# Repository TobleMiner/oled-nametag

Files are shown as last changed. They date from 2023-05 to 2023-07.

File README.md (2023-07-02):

OLED Nametag
============

This repository contains the design file for a fully open source
electronic name badge with monochrome OLED display.  

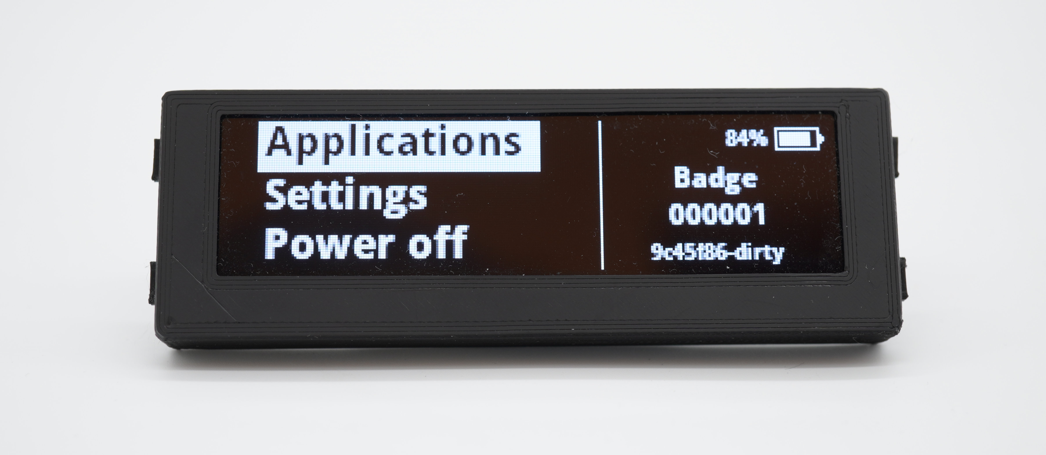
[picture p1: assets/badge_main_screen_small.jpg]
Image of badge in operation


**I would not recommend ordering RevA yet as there are a number of
issues with that version. See
[Rev A issues](https://github.com/TobleMiner/oled-nametag#rev-a-issues)
for details.**

# Features

 - Bright, sunlight readable OLED display
 - Infinity constrast ratio
 - Support for GIF animations
 - WLAN AP support
 - Web interface for management of animations
 - Automatic brightness adjustment
 - 8h+ runtime

# Construction

All fabrication files are located in `fab`.  

## PCB

The main PCB have been optimized for manufacturing through JLCPCB.  
Most components can also be assmbled by JLCPCB directly.  

## Display

The display used can be one of:
 - UG-5664ALBEF01
 - UG-5664ASWEF01
 - ER-OLED032-1 (all variants)

Other menchanically compatible SSD1322-based parts can also be used.

## Housing

The device housing is 3D printable and designed to suit most 3D printing
processes, especially SLA and FDM. Good results have also been achieved with
MJF and SLS printing.  

There are three different fabrication files for the case top part,
depending on the thickness of the lithium batteries used.  

Additionally 4 button actuators need to be printed for each OLED badge.
Those are also contained in the OpenSCAD design files and fabrication
output.

# Assembly

## PCB

When choosing PCB assembly through JLCPCB only two PCB components need to
be assmbled manually:
 - WLAN antenna (AE1)
 - Ambient light sensor (U4)

## Display

The display is mounted to the top side of the PCB using double sided
adhesive tape with a thickness of .15mm. Align to top of the PCB (side
with USB-C port) with the top of the display.

## Batteries

The device needs two 303030, 403030 or 503030 cells as a power source.  
The batteries need to be mounted on the bottom side of the PCB. Double-
sided adhesive foam tape with a thickness of 2mm is recommended for this
purpose.

## Housing

Place the button actuators into the housing first, then slide in the PCB
with both display and batteries attached and stuck down.  

At this point the badge should look like this:  
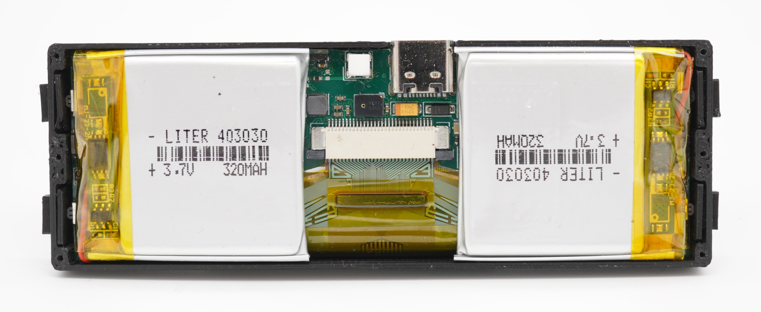
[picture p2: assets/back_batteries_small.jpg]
Image of backside with top removed


Finally screw on the top lid iwht six 4mm M1 fine thread self tapping
screws.

# Firmware

The OLED badge is running fully Open Source firmware. For the purpose of
enabling WLAN connectivity vendor-provided binary blobs are required.  
The firmware source can be found here:  
[https://github.com/TobleMiner/oled-nametag-firmware](https://github.com/TobleMiner/oled-nametag-firmware)

# Rev A issues

Rev A is very much a prototype. It has the following known issues:
 - USB D- and D+ are swapped on the ESP32-S3, needs bodge to swap data lines
 - OLED SPI mode is inconvenient and incompatible with current firmware, connect R1 to GND
 - R21 is too large, preventing soft power down, replace with 1k

The current state of the repository does not reflect Rev A but a
potential Rev B. Please note that this state of the design has not been
tested yet.

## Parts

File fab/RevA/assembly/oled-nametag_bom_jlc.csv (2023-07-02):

Comment | Designator | Footprint | LCSC Part #
10uF | C4,C5,C28,C30,C31,C32,C13,C18,C26 | C_0402_1005Metric | C15525
10uF 25V | C8,C3,C6 | C_0603_1608Metric | C96446
10pF | C11,C12 | C_0402_1005Metric | C32949
1uF | C23,C29,C1,C7,C10,C15,C40 | C_0402_1005Metric | C52923
1nF | C24 | C_1206_3216Metric | C35216
100nF | C25,C27,C34,C35,C36,C37,C38,C2,C39,C9,C14,C16,C17,C21,C22 | C_0402_1005Metric | C1525
10uF | C33 | CP_EIA-3216-10_Kemet-I | C7171
1N5819WS | D2,D1 | D_SOD-323 | C191023
B5819W | D3 | D_SOD-123 | C8598
BAV70 | D4 | SOT-23 | C68978
1N4148WS | D5 | D_SOD-323 | C2128
2A | F2,F3 | R_0603_1608Metric | C96542
Bead | FB1 | L_0805_2012Metric | C1015
USB_C_Receptacle_USB2.0 | J1 | USB_C_Receptacle_Palconn_UTC16-G | C167321
10uH | L1 | L_1210_3225Metric | C703786
0R | L2 | L_0402_1005Metric | C17168
2.2uH | L3 | L_Taiyo-Yuden_MD-3030 | C43389
AO3401A | Q1,Q2 | SOT-23 | C15127
FS8205A | Q3 | SOT-23-6 | C2830320
2N7002 | Q6 | SOT-23 | C8545
680k | R2 | R_0603_1608Metric | C25822
50R | R3 | R_0402_1005Metric | C25120
47k | R4,R10,R11,R21,R6 | R_0402_1005Metric | C25792
0R | R7 | R_0402_1005Metric | C17168
1k | R12,R14 | R_0402_1005Metric | C11702
470R | R13 | R_0402_1005Metric | C25117
10k | R15,R17,R30,R33,R29 | R_0402_1005Metric | C25744
200k | R18 | R_0805_2012Metric | C17539
5.1k | R19,R20,R5,R28,R8,R9,R16,R31 | R_0402_1005Metric | C25905
10mR | R26 | R_0805_2012Metric | C5185583
100R | R27,R22,R23,R24,R25,R32,R1 | R_0402_1005Metric | C25076
Power | SW1 | SW_SPST_B3U-3000P-B | C963349
BTN1 | SW2 | SW_SPST_B3U-3000P-B | C963349
BTN2 | SW3 | SW_SPST_B3U-3000P-B | C963349
BTN3 | SW4 | SW_SPST_B3U-3000P-B | C963349
~ | U1 | FFC_30P_TC_P0.5mm_0.5K-AS-30PWB | C2911772
W25Q128 | U2 | WSON-8-1EP_6x5mm_P1.27mm_EP3.4x4.3mm | C2689660
ESP32-S3 | U3 | QFN-56-1EP_7x7mm_P0.4mm_EP4x4mm_ThermalVias | C2913192
~ | U5 | ST_HCLGA-4LD_3x4mm | C966942
TPS61040DBV | U6 | SOT-23-5 | C7722
DW01+G | U7 | SOT-23-6 | C14213
BQ24081 | U8 | Texas_DRC0010J_ThermalVias | C555156
SRV05-4 | U9 | SOT-23-6 | C85364
BQ27546 | U10 | DSBGA-15_BQ27546_I2C_1.95x2.6mm_P0.5mm | C528629
TPS63001 | U11 | Texas_DRC0010J_ThermalVias | C28060
40MHz | Y1 | Crystal_SMD_2016-4Pin_2.0x1.6mm | C255898

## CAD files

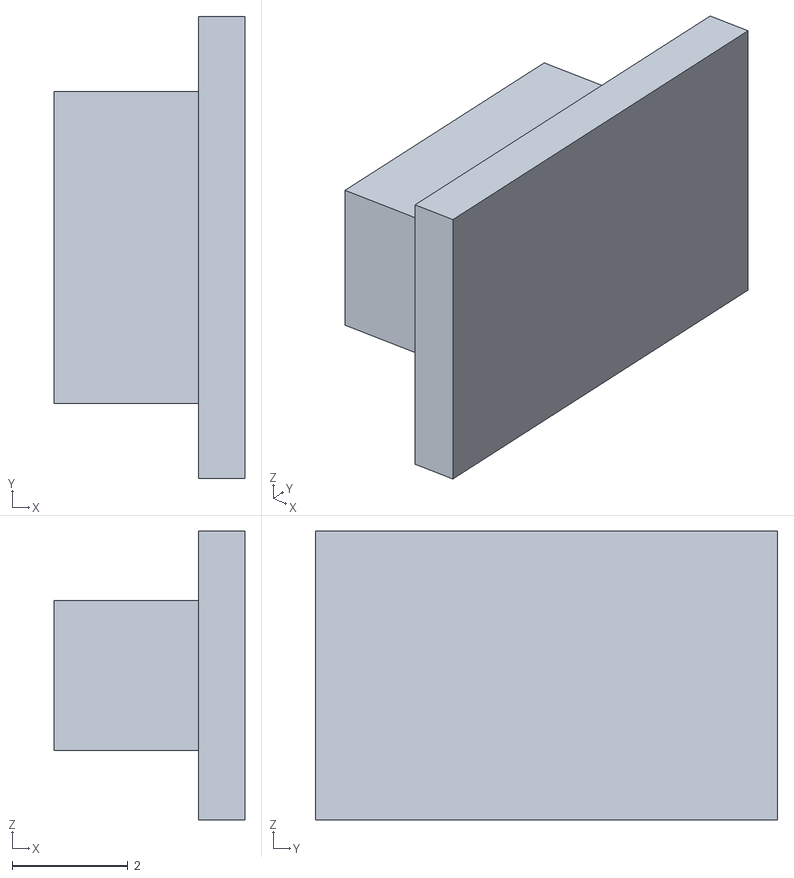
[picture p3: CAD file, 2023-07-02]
fab/RevA/3dprinting/oled-badge-case_button_rev1.4.stl
3.30 x 8.00 x 5.00

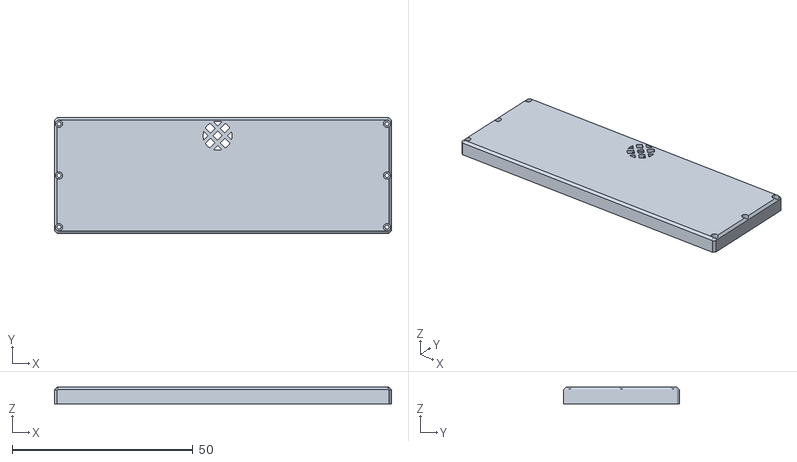
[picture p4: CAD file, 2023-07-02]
fab/RevA/3dprinting/oled-badge-case_top_rev2.1_503030.stl
93.2 x 32.0 x 4.60

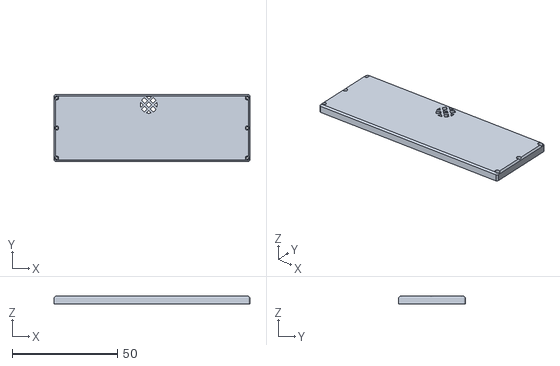
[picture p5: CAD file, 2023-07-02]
fab/RevA/3dprinting/oled-badge-case_top_rev2.1_403030.stl
93.2 x 32.0 x 3.60

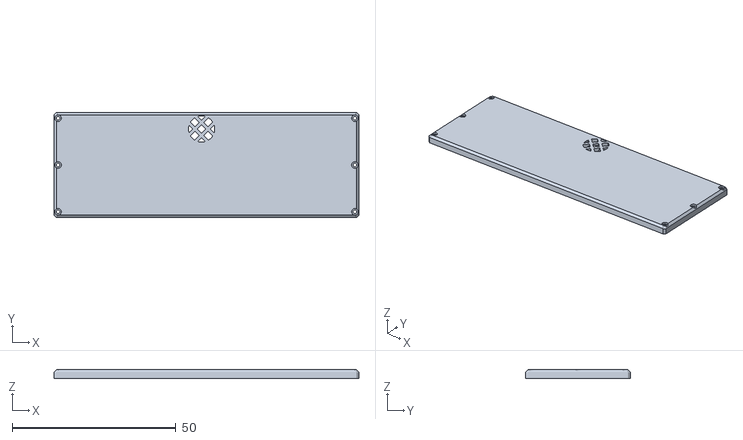
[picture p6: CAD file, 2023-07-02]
fab/RevA/3dprinting/oled-badge-case_top_rev2.1_303030.stl
93.2 x 32.0 x 2.60

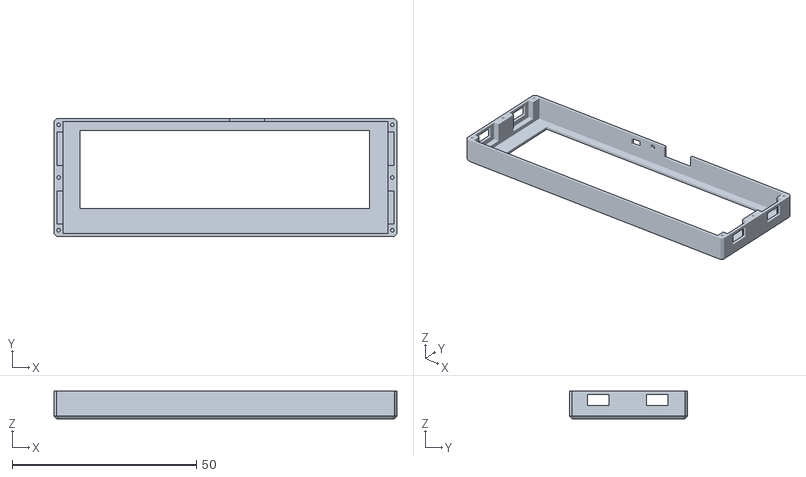
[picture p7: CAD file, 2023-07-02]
fab/RevA/3dprinting/oled-badge-case_bottom_rev1.9_tapered.stl
93.2 x 32.0 x 7.50

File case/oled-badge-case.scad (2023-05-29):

ESCAPE_HOLES = true;
BATTERY_THICKNESS = 4;
WALL_THICKNESS_FRONT_BACK = 0.8;
WALL_THICKNESS_LEFT_RIGHT = 0.8;
WALL_THICKNESS_TOP = 0.8;
WALL_THICKNESS_BOTTOM = 0.8;
BOARD_WIDTH = 88;
BOARD_HEIGHT = 30;
BOARD_DEPTH = 4.5 + BATTERY_THICKNESS;
CASE_HEIGHT_BOTTOM = 6.7;
CASE_HEIGHT_TOP = 0.8 + BATTERY_THICKNESS - 3;
BOARD_OVERSIZE = 0.4;
BUTTON_BASE_THICKNESS = 0.8;
BUTTON_ACTUATOR_LENGTH = 0.8;
BUTTON_ACTUATION = 0.6;
SCREW_HEAD_SIZE = 2; // non-oversized: 2
SCREW_HOLE_SIZE = 1.1; // non-oversized: 1.1
SCREW_THREAD_SIZE = 0.9; // non-oversized: 0.9
/* Anycubic Kossel settings
SCREW_HEAD_SIZE = 2.5; // non-oversized: 2
SCREW_HOLE_SIZE = 1.5; // non-oversized: 1.1
SCREW_THREAD_SIZE = 1; // non-oversized: 0.9
*/

module button() {
    color("brown") {
        translate([0 - 4, 0, -1.5]) cube([4, 5.8, 3]);
        translate([0, 0 - 1.1 - 0.5, -2.5 - 0.5]) cube([BUTTON_BASE_THICKNESS + 0.01, 9, 6]);
    }
}

module button_mirrored() {
    color("brown") {
        translate([BUTTON_BASE_THICKNESS, 0, -1.5]) cube([4, 5.8, 3]);
        translate([-0.01, 0 - 1.1 - 0.5, -2.5 - 0.5]) cube([BUTTON_BASE_THICKNESS + 0.01, 9, 6]);
    }
}

module switch_and_button() {
    translate([0, 0 - 0.6 + 0.1, 0.6]) button();
}

module switch_and_button_mirrored() {
    translate([0, 0 - 0.6 + 0.1, 0.6]) button_mirrored();
}

module board() {
    body_width = BOARD_WIDTH + BOARD_OVERSIZE;
    body_height = BOARD_HEIGHT + BOARD_OVERSIZE;
    translate([0, 0, 2 + 0.15 + 1]) translate([0, 0, 0.5]) {
        // Buttons left
        translate([0, 4.6, 0]) switch_and_button();
        translate([0, 20.6, 0]) switch_and_button();
        translate([BUTTON_BASE_THICKNESS, 4.6, 0]) switch_and_button();
        translate([BUTTON_BASE_THICKNESS, 20.6, 0]) switch_and_button();
    }

    translate([BUTTON_BASE_THICKNESS + BUTTON_ACTUATOR_LENGTH, 0, 0]) {
        // Main body
        cube([body_width, body_height, BOARD_DEPTH]);
        // Display cutout
        translate([0, 2.2, -2]) translate([4.61, 4.62, 0]) cube([78.78, 21.18, 2]);
        translate([0, 0, 2 + 0.15 + 1]) {
            // Antenna
            translate([39, 26, 0]) cube([3, 3, 4]);
            // USB-C port
            translate([45.5 - 0.25, 30, 0]) cube([9.5, 2, 3.6]);
            // Audio port
            // translate([41, 30 + 3, 2]) rotate([90, 0, 0]) cylinder(3, 0.75, 0.75, $fn=100);
            // Light sensor
            translate([33.5, 30, 0.25]) cube([3, 2, 1.5 + 0.5]);
            translate([0, 0, 0.5]) {
                // Buttons right
                translate([body_width, 4.6, 0]) switch_and_button_mirrored();
                translate([body_width, 20.6, 0]) switch_and_button_mirrored();
                translate([body_width + BUTTON_BASE_THICKNESS, 4.6, 0]) switch_and_button_mirrored();
                translate([body_width + BUTTON_BASE_THICKNESS , 20.6, 0]) switch_and_button_mirrored();
            }
        }
    }
}

module screw_thread() {
    cylinder(5, SCREW_THREAD_SIZE/2, SCREW_THREAD_SIZE/2, $fn=100);
    if (ESCAPE_HOLES) {
        translate([0, 0, 0.75 -0.1]) rotate([0, 90, 0]) cylinder(3, 0.75, 0.75, $fn=100);
    }
}

module screw_hole() {
    cylinder(100, SCREW_HOLE_SIZE/2, SCREW_HOLE_SIZE/2, $fn=100);
    translate([0, 0, 2]) cylinder(100, SCREW_HEAD_SIZE/2, SCREW_HEAD_SIZE/2, $fn=100);
}

module top_cover() {
    width = BOARD_WIDTH + BOARD_OVERSIZE + WALL_THICKNESS_LEFT_RIGHT * 2 + BUTTON_ACTUATOR_LENGTH * 2 + BUTTON_BASE_THICKNESS * 2;
    height = BOARD_HEIGHT + BOARD_OVERSIZE + WALL_THICKNESS_FRONT_BACK * 2;
    depth = CASE_HEIGHT_TOP /* board */ + 1 /* magnet */ + WALL_THICKNESS_TOP;
    mic_pos = [width / 2 - 1.5, height - (8 + 1 - 4), CASE_HEIGHT_TOP];
    difference() {
        cube([width, height, depth]);
        union() {
            // microphone grid hole
            translate(mic_pos) mic_hole();
            // magnet detent
            translate([width / 2 - 41/2, height / 2 - 13/2, CASE_HEIGHT_TOP]) cube([41, 13, 1.2]);
            // weight reduction
            translate([7, 3, CASE_HEIGHT_TOP]) {
                difference() {
                    cube([width - 14, height - 6, 1.2]);
                    translate([(width - 14 - 50) / 2, (height - 6 - 20) / 2, 0]) cube([50, 20, 1.2]);
                }
            }
            // screw holes
            translate([1.25, 1.7, 0]) screw_hole();
            translate([1.25, height / 2, 0]) screw_hole();
            translate([1.25, height - 1.7, 0]) screw_hole();
            translate([width - 1.25, 1.7, 0]) screw_hole();
            translate([width - 1.25, height / 2, 0]) screw_hole();
            translate([width - 1.25, height - 1.7, 0]) screw_hole();
        };
    }
    // microphone grid
    difference() {
        translate(mic_pos) grid(WALL_THICKNESS_TOP + 1);
        // weight reduction
        translate([7, 3, CASE_HEIGHT_TOP]) {
            difference() {
                cube([width - 14, height - 6, 1.2]);
                translate([(width - 14 - 50) / 2, (height - 6 - 20) / 2, 0]) cube([50, 20, 1.2]);
            }
        }
    }
}

module bottom_shell() {
    width = BOARD_WIDTH + BOARD_OVERSIZE + WALL_THICKNESS_LEFT_RIGHT * 2 + BUTTON_ACTUATOR_LENGTH * 2 + BUTTON_BASE_THICKNESS * 2;
    height = BOARD_HEIGHT + BOARD_OVERSIZE + WALL_THICKNESS_FRONT_BACK * 2;
    difference() {
        // bottom shell
        cube([width, height, WALL_THICKNESS_BOTTOM + CASE_HEIGHT_BOTTOM]);
        translate([0, 0, WALL_THICKNESS_BOTTOM + CASE_HEIGHT_BOTTOM - 4]) {
            // screw holes (4mm deep)
            translate([1.25, 1.7, 0]) screw_thread();
            translate([1.25, height / 2, 0]) screw_thread();
            translate([1.25, height - 1.7, 0]) screw_thread();
            translate([width - 1.25, 1.7, 0]) rotate([0, 0, 180]) screw_thread();
            translate([width - 1.25, height / 2, 0]) rotate([0, 0, 180]) screw_thread();
            translate([width - 1.25, height - 1.7, 0]) rotate([0, 0, 180]) screw_thread();
        }
    }
}

module grid_bar(height) {
    translate([-4, -0.5, 0]) cube([8, 1, height]);
}

module grid(height) {
    translate([-1, 1, 0]) rotate([0, 0, 45]) grid_bar(height);
    translate([1, -1, 0]) rotate([0, 0, 45]) grid_bar(height);
    translate([-1,-1, 0]) rotate([0, 0, -45]) grid_bar(height);
    translate([1, 1, 0]) rotate([0, 0, -45]) grid_bar(height);
}

module mic_hole() {
    cylinder(2, 4, 4, $fn=100);
}

module taper_bar() {
    cube([100, 100, 1], center=true);
}

module taper_shell() {
    width = BOARD_WIDTH + BOARD_OVERSIZE + WALL_THICKNESS_LEFT_RIGHT * 2 + BUTTON_ACTUATOR_LENGTH * 2 + BUTTON_BASE_THICKNESS * 2;
    height = BOARD_HEIGHT + BOARD_OVERSIZE + WALL_THICKNESS_FRONT_BACK * 2;
    depth = CASE_HEIGHT_TOP + 1 + WALL_THICKNESS_TOP + CASE_HEIGHT_BOTTOM + WALL_THICKNESS_BOTTOM;
    
    translate([width/2, 0, 0]) rotate([-45, 0, 0]) taper_bar();
    translate([width/2, height, 0]) rotate([45, 0, 0]) taper_bar();
    translate([0, height/2, 0]) rotate([0, 45, 0]) taper_bar();
    translate([width, height/2, 0]) rotate([0, -45, 0]) taper_bar();

    translate([0, 0, depth]) {
        translate([width/2, 0, 0]) rotate([45, 0, 0]) taper_bar();
        translate([width/2, height, 0]) rotate([-45, 0, 0]) taper_bar();
        translate([0, height/2, 0]) rotate([0, -45, 0]) taper_bar();
        translate([width, height/2, 0]) rotate([0, 45, 0]) taper_bar();

        translate([0, 0, 0]) translate([0.25, 0.25, -0.25]) rotate([45, 0, -45]) taper_bar();
        translate([0, height, 0]) translate([0.25, -0.25, -0.25]) rotate([-45, 0, 45]) taper_bar();
        translate([width, 0, 0]) translate([-0.25, 0.25, -0.25]) rotate([45, 0, 45]) taper_bar();
        translate([width, height, 0]) translate([-0.25, -0.25, -0.25]) rotate([-45, 0, -45]) taper_bar();
    }

    translate([0, 0, depth/2]) rotate([90, 0, -45]) taper_bar();
    translate([0, height, depth/2]) rotate([90, 0, 45]) taper_bar();
    translate([width, height, depth/2]) rotate([90, 0, -45]) taper_bar();
    translate([width, 0, depth/2]) rotate([90, 0, 45]) taper_bar();

    translate([0, 0, 0]) translate([0.25, 0.25, 0.25]) rotate([-45, 0, -45]) taper_bar();
    translate([0, height, 0]) translate([0.25, -0.25, 0.25]) rotate([45, 0, 45]) taper_bar();
    translate([width, 0, 0]) translate([-0.25, 0.25, 0.25]) rotate([-45, 0, 45]) taper_bar();
    translate([width, height, 0]) translate([-0.25, -0.25, 0.25]) rotate([45, 0, -45]) taper_bar();
}

module case(top ,bottom) {
    difference() {
        bottom_shell_height = WALL_THICKNESS_BOTTOM + CASE_HEIGHT_BOTTOM;
        union() {
            if (bottom) { color("green") bottom_shell(); }
            if (top) { translate([0, 0, bottom_shell_height]) color("red") top_cover(); }
        }
        translate([WALL_THICKNESS_LEFT_RIGHT, WALL_THICKNESS_FRONT_BACK, WALL_THICKNESS_BOTTOM]) board();
    }
}
/*
    translate([WALL_THICKNESS_LEFT_RIGHT, WALL_THICKNESS_FRONT_BACK, WALL_THICKNESS_TOP]) color("white") board();
*/
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

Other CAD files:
case/oled-badge-case_reverse-mount.scad

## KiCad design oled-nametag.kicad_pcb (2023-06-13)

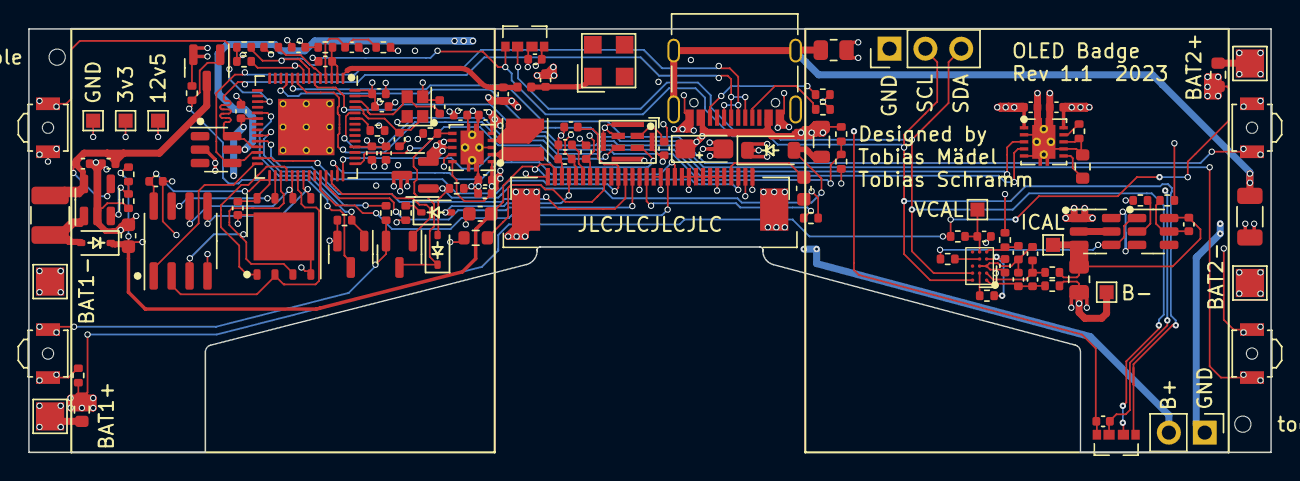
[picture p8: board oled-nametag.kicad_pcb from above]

Board: 4 copper layers, 88.0 x 30.0 mm, 123 parts (0 on the bottom side), 78 nets.

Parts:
AE1: Antenna_Shield; 2065130001
C1, C7, C10, C15, C23, C29, C40: 1uF; C_0402_1005Metric
C2, C9, C14, C16, C17, C21, C22, C25, C27, C34, C35, C36, C37, C38, C39, C41: 100nF; C_0402_1005Metric
C3, C6, C8: 10uF 25V; C_0603_1608Metric
C4, C5, C13, C18, C26, C28, C30, C31, C32: 10uF; C_0402_1005Metric
C11, C12: 10pF; C_0402_1005Metric
C19, C20: DNP; C_0402_1005Metric
C24: 1nF; C_1206_3216Metric
C33: 10uF; CP_EIA-3216-10_Kemet-I
D1, D2: 1N5819WS; D_SOD-323
D3: B5819W; D_SOD-123
D4: BAV70; SOT-23
D5: 1N4148WS; D_SOD-323
F2, F3: 2A; R_0603_1608Metric
FB1: Bead; L_0805_2012Metric
H1, H2: ToolingHole; ToolingHole_JLCSMT
J1: USB_C_Receptacle_USB2.0; USB_C_Receptacle_Palconn_UTC16-G
J2: I2C; PinHeader_1x03_P2.54mm_Vertical
J3: LOAD; PinHeader_1x02_P2.54mm_Vertical
L1: 10uH; L_1210_3225Metric
L2: 0R; L_0402_1005Metric
L3: 2.2uH; L_Taiyo-Yuden_MD-3030
Q1, Q2: AO3401A; SOT-23
Q3: FS8205A; SOT-23-6
Q6: 2N7002; SOT-23
R1, R22, R23, R24, R25, R27, R32: 100R; R_0402_1005Metric
R2: 680k; R_0603_1608Metric
R3: 50R; R_0402_1005Metric
R4, R6, R10, R11: 47k; R_0402_1005Metric
R5, R8, R9, R16, R19, R20, R28, R31: 5.1k; R_0402_1005Metric
R7: 0R; R_0402_1005Metric
R12, R21: 1k; R_0402_1005Metric
R13: 470R; R_0402_1005Metric
R14: 2.7k; R_0603_1608Metric
R15, R17, R29, R30, R33: 10k; R_0402_1005Metric
R18: 200k; R_0805_2012Metric
R26: 10mR; R_0805_2012Metric
SW1: Power; SW_SPST_B3U-3000P-B
SW2: BTN1; SW_SPST_B3U-3000P-B
SW3: BTN2; SW_SPST_B3U-3000P-B
SW4: BTN3; SW_SPST_B3U-3000P-B
TP1: ICAL-; TestPoint_Pad_1.0x1.0mm
TP2, TP4: BAT+; TestPoint_Pad_2.0x2.0mm
TP3, TP5: BAT-; TestPoint_Pad_2.0x2.0mm
TP6: ICAL+; TestPoint_Pad_1.0x1.0mm
TP7: +12v5; TestPoint_Pad_1.0x1.0mm
TP8: +3v3; TestPoint_Pad_1.0x1.0mm
TP9: GND; TestPoint_Pad_1.0x1.0mm
TP10: VCAL; TestPoint_Pad_1.0x1.0mm
U1: FFC_30P_TC_P0.5mm_0.5K-AS-30PWB
U2: W25Q128; WSON-8-1EP_6x5mm_P1.27mm_EP3.4x4.3mm
U3: ESP32-S3; QFN-56-1EP_7x7mm_P0.4mm_EP4x4mm_ThermalVias_0.3mm
U4, U13: VEML3235SL
U5: ST_HCLGA-4LD_3x4mm
U6: TPS61040DBV; SOT-23-5
U7: DW01+G; SOT-23-6
U8: BQ24081; Texas_DRC0010J_ThermalVias.3
U9: SRV05-4; SOT-23-6
U10: BQ27546; DSBGA-15_BQ27546_I2C_1.95x2.6mm_P0.5mm
U11: TPS63001; Texas_DRC0010J_ThermalVias.3
U12: ESP-PSRAM32; SOIC-8_3.9x4.9mm_P1.27mm
Y1: 40MHz; Crystal_SMD_2016-4Pin_2.0x1.6mm

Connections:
+3V3: C1.1, C2.1, C13.2, C15.1, C16.2, C17.2, C18.2, C21.2, C22.2, C26.2, C30.2, C31.2, C41.2, R6.1, R7.2, R8.1, R9.1, R31.1, TP8.1, U1.24 (VDDIO), U1.26 (VCI), U3.20 (VDD3P3_RTC), U3.46 (VDD3P3_CPU), U3.55 (VDDA), U3.56 (VDDA), U4.1 (VDD), U5.1 (VDD), U11.1 (VOUT), U11.10 (FB), U13.1 (VDD)
+BATT: C27.2, F2.2, F3.2, J3.2, Q1.3 (D), R13.1, R22.1, R23.1, R27.1, U8.10 (OUT)
/ESP32/D+: J1.A6 (D+), J1.B6 (D+), U3.26 (GPIO20), U9.4 (IO3)
/ESP32/D-: J1.A7 (D-), J1.B7 (D-), U3.25 (GPIO19), U9.6 (IO4)
/ESP32/OLED_CLK: U1.13 (D0/CLK), U3.38 (GPIO33)
/ESP32/OLED_CS: U1.19 (~CS), U3.24 (GPIO18)
/ESP32/OLED_DATA: U1.12 (D1/SIN), U3.41 (GPIO36)
/ESP32/OLED_DC: U1.18 (D/~C), U3.39 (GPIO34)
/ESP32/OLED_EN: Q6.1 (G), R10.1, U3.19 (GPIO14)
/ESP32/OLED_RST: C39.2, U1.20 (~RES), U3.27 (GPIO21)
/ESP32/PDM_CLK: U3.43 (GPIO38), U5.3 (CLK)
/ESP32/PDM_DATA: U3.42 (GPIO37), U5.4 (DATA)
/ESP32/PWR_EN: D4.1 (A), U3.40 (GPIO35)
/ESP32/PWR_ON: D4.2 (A), R29.2, SW1.2
/ESP32/SCL: J2.2, R8.2, U3.7 (GPIO2), U4.4 (SCL), U10.A3 (SCL), U13.4 (SCL)
/ESP32/SDA: J2.3, R9.2, U3.8 (GPIO3), U4.3 (SDA), U10.B3 (SDA), U13.3 (SDA)
/ESP32/USB_DET: R28.1, R30.1, U3.9 (GPIO4)
/ESP32/VDD_SPI: C10.1, C40.1, U2.8 (VCC), U3.29 (VDD_SPI), U12.8 (VCC)
/ESP32/~BTN1: SW2.2, U3.17 (GPIO12)
/ESP32/~BTN2: SW3.2, U3.11 (GPIO6)
/ESP32/~BTN3: SW4.2, U3.10 (GPIO5)
/ESP32/~CHRG: U3.6 (GPIO1), U8.3 (STAT1)
/ESP32/~RST: C9.1, R6.2, U3.4 (CHIP_PU)
/ESP32/~STAT2: U3.52 (GPIO46), U8.4 (STAT2)
/Power/DSG: R32.2, U10.D2 (CE)
GND: C1.2, C2.2, C3.2, C4.1, C5.1, C6.1, C7.2, C8.2, C9.2, C10.2, C11.2, C12.1, C13.1, C14.2, C15.2, C16.1, C17.1, C18.1, C19.1, C20.1, C21.1, C22.1, C23.2, C24.1, C26.1, C27.1, C28.1, C30.1, C31.1, C32.1, C33.2, C39.1, C40.2, C41.1, J1.A1 (GND), J1.A12 (GND), J1.B1 (GND), J1.B12 (GND), J2.1, J3.1, Q3.1, Q6.2 (S), R1.1, R2.2, R3.1, R5.1, R10.2, R12.1, R14.1, R15.2, R16.2, R17.2, R18.1, R19.2, R20.1, R21.2, R30.2, SW2.1, SW3.1, SW4.1, TP9.1, U1.1 (SHIELD), U1.2 (VSS), U1.5 (VLSS), U1.6 (D7), U1.7 (D6), U1.8 (D5), U1.9 (D4), U1.10 (D3), U1.11 (D2), U1.14 (E/~RD), U1.15 (R/~W), U1.17 (BS1), U1.28 (VLSS), U1.30 (SHIELD), U1.ML (MP), U2.4 (GND), U2.9 (EP), U3.57 (GND), U4.2 (GND), U5.2 (L/R), U5.5 (GND), U6.2 (GND), U8.2 (GND), U8.5 (GND), U8.7 (GND), U8.8 (~TE), U8.11 (GND), U9.2 (VN), U11.3 (PGND), U11.9 (GND), U11.11 (PGND), U12.4 (VSS), U13.2 (GND), Y1.2, Y1.4
GND1: C29.1, C34.2, C35.2, C37.1, C38.2, R25.1, R26.1, TP3.1, TP5.1, TP6.1, U1.MR (MP), U10.C1 (VSS), U10.C2 (VSS)
unnamed: AE1.1 (A), C19.2, L2.2
unnamed: D1.2 (A), U1.27 (VSL)
unnamed: D1.1 (K), R3.2
unnamed: D2.2 (A), L1.2, U6.1 (SW)
unnamed: D3.2 (A), D5.2 (A), FB1.2, Q1.1 (G), R21.1
unnamed: C28.2, C32.2, D3.1 (K), Q1.2 (S), Q2.2 (S), R11.2, U11.5 (VIN), U11.7 (PS/SYNC), U11.8 (VINA)
unnamed: D4.3 (K), D5.1 (K), R17.1, U11.6 (EN)
unnamed: F2.1, TP2.1
unnamed: F3.1, TP4.1
unnamed: J1.A5 (CC1), R19.1
unnamed: J1.B5 (CC2), R20.2
unnamed: C24.2, J1.S1 (SHIELD), R18.2
unnamed: C4.2, C5.2, L1.1, Q2.3 (D), U6.4 (EN), U6.5 (VIN)
unnamed: Q2.1 (G), Q6.3 (D), R11.1
unnamed: R27.2, SW1.1
unnamed: R1.2, U1.16 (BS0)
unnamed: R2.1, U1.22 (IREF)
unnamed: C6.2, U1.4 (VCOMH)
unnamed: C7.1, U1.25 (VDD)
unnamed: U2.1 (~CS), U3.32 (SPICS0)
unnamed: R31.2, U3.5 (GPIO0)
unnamed: R29.1, U3.23 (GPIO17)
unnamed: R16.1, U3.51 (GPIO45)
unnamed: C20.2, L2.1, U3.1 (LNA_IN)
unnamed: C11.1, U3.53 (XTAL_N), Y1.1
unnamed: C12.2, U3.54 (XTAL_P), Y1.3
unnamed: R4.2, R5.2, U6.3 (FB)
unnamed: Q3.6, U7.3 (CO)
unnamed: Q3.4, R32.1, U7.1 (DO)
unnamed: C25.2, R13.2, U7.5 (VDD)
unnamed: R12.2, U7.2 (VM)
unnamed: C25.1, Q3.3, R24.1, R26.2, TP1.1, U7.6 (VSS)
unnamed: R14.2, U8.6 (ISET)
unnamed: R15.1, U8.9 (TS)
unnamed: C35.1, R23.2, TP10.1, U10.E2 (BAT)
unnamed: C34.1, R22.2, U10.E1 (REGIN)
unnamed: C36.2, C38.1, R24.2, U10.B1 (SRN)
unnamed: C36.1, C37.2, R25.2, U10.A1 (SRP)
unnamed: R33.1, U10.B2 (TS)
unnamed: C29.2, R33.2, U10.D1 (VCC)
unnamed: L3.1, U11.4 (L1)
unnamed: L3.2, U11.2 (L2)
unnamed: U2.6 (CLK), U3.33 (SPICLK), U12.6 (SCLK)
unnamed: U2.3 (IO2), U3.31 (SPIWP), U12.3 (SIO2)
unnamed: U2.7 (IO3), U3.30 (SPIHD), U12.7 (SIO3)
unnamed: U2.5 (DI(IO0)), U3.35 (SPID), U12.5 (SI/SIO)
unnamed: U2.2 (DO(IO1)), U3.34 (SPIQ), U12.2 (SO/SIO)
unnamed: U3.28 (SPICS1), U12.1 (~CE)
VBUS: C23.1, C33.1, FB1.1, J1.A4 (VBUS), J1.A9 (VBUS), J1.B4 (VBUS), J1.B9 (VBUS), R28.2, U8.1 (IN), U9.5 (VP)
VCC: C3.1, C8.1, D2.1 (K), R4.1, TP7.1, U1.3 (VCC), U1.29 (VCC)
VDD3P3: C14.1, R7.1, U3.2 (VDD3P3), U3.3 (VDD3P3)

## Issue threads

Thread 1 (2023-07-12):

Looking to help

mikestanczyk, 2023-07-12:
I hate to contact you this way but github doesn't make it easy.  I'd like to discuss with you about if you're ready to accept help and what kind of help you need and are ready to accept. This is the first open source project I've been passionate enough about to actively contribute to.

I realize you maybe uncomfortable discuss this openly.  I'm open to discussing this privately.

Thanks
Mike

srem1, 2023-07-20:
meybe wire, matrix, tox, simplex channel

In my opinion power is important, and meybe add cc1101 or lora (meshtastic , reticullum) and(or) some mesh wifi (for example BATMAN)

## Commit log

2023-04-23 Finish ESP32 fanout
    [esp32.kicad_sch, oled-nametag.kicad_pcb, power.kicad_sch]
2023-04-23 Add power planes
    [oled-nametag.kicad_pcb]
2023-04-24 Finish first layout revision
    [oled-nametag.kicad_pcb, oled-nametag.kicad_sch, oled.kicad_sch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]
2023-04-24 Make EDRC happy (mostly)
    [esp32.kicad_sch, oled-nametag.kicad_pcb, power.kicad_sch]
2023-04-24 Add 3D models
    [oled-nametag.kicad_pcb]
2023-04-24 Make DRC happy (for the most part)
    [oled-nametag.kicad_pcb]
2023-04-24 Add fuel gauge thermistor
    [oled-nametag.kicad_pcb, power.kicad_sch]
2023-04-24 Add power rail testpoints
    [oled-nametag.kicad_pcb, oled-nametag.kicad_sch, power.kicad_sch]
2023-04-24 Add PSRAM
    Doom?
    [esp32.kicad_sch, oled-nametag.kicad_pcb]
2023-04-24 Fix fuel gauge thermistor ground reference
    [oled-nametag.kicad_pcb, power.kicad_sch]
2023-04-24 Add pin 1 and polarity indicators
    [oled-nametag.kicad_pcb]
2023-04-24 Add missing LCSC partnumbers
    [oled-nametag.kicad_sch, power.kicad_sch]
2023-04-24 Add silkscreen markings
    [oled-nametag.kicad_pcb]
2023-04-24 Adjust to new JLC manufacturing requirements
    Change default minimum via hole size to .3mm
    Replace package thermal vias by .3mm via
    [esp32.kicad_sch, oled-nametag.kicad_pcb, power.kicad_sch]
2023-04-28 Hide U11 designator
    [oled-nametag.kicad_pcb]
2023-04-30 Hide U8 designator
    [oled-nametag.kicad_pcb]
2023-05-01 Hide U3 designator
    [oled-nametag.kicad_pcb]
2023-05-07 Start rev1.1
    Fixed bugs:
    - Swapped D+ and D-
    - Insufficient pull-down strength on VBUS
    - Default OLED to 4-wire SPI
    - Swap VBUS detect divider from 2/3 to 1/3
    [esp32.kicad_sch, oled-nametag.kicad_pcb, oled.kicad_sch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]
2023-05-08 More Rev 1.1 fixes
    - Revert USB_DET voltage divider swap
    - Fix battery gauge temperature sensor reference level
    [oled-nametag.kicad_pcb, power.kicad_sch]
2023-05-09 Reduce charge current to 300mA, Add battery voltage calibration testpoint
    [oled-nametag.kicad_pcb, power.kicad_sch]
2023-05-16 Add initial case design
    [oled-badge-case.scad]
2023-05-16 case: make model parameterizeable
    [oled-badge-case.scad]
2023-05-16 case: support configuring board depth and oversize
    [oled-badge-case.scad]
2023-05-17 case: make board height and screw hole size configureable
    [oled-badge-case.scad]
2023-05-29 case: make battery thickness configureable
    [oled-badge-case.scad]
2023-05-29 Add current calibration output
    [oled-nametag.kicad_pcb, power.kicad_sch]
2023-06-13 Add second light sensor position for reversed device mounting
    [esp32.kicad_sch, oled-nametag.kicad_pcb, power.kicad_sch]
2023-06-13 Add experimental case with reverse mounting option
    [oled-badge-case_reverse-mount.scad]
2023-07-02 Add RevA fabrication files
    [oled-badge-case_bottom_rev1.9_tapered.stl, oled-badge-case_button_rev1.4.stl, oled-badge-case_top_rev2.1_303030.stl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]
